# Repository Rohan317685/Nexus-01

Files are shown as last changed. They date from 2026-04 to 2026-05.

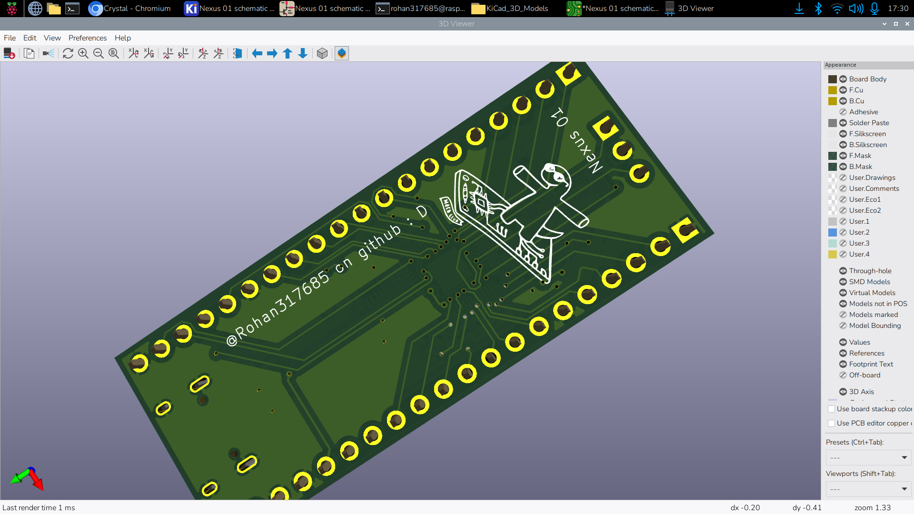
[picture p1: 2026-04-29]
images/2026-04-29-173034_1920x1080_scrot.png

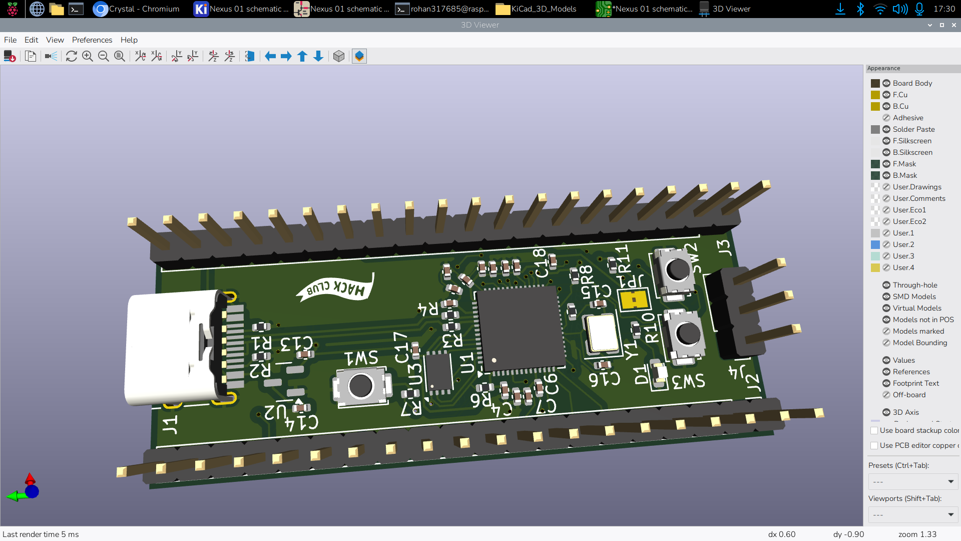
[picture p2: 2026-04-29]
images/2026-04-29-173029_1920x1080_scrot.png

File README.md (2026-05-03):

<h1 align="center">
  <br>
  Nexus 01</a>
  <br>
  Nexus 01
  <br>
</h1>

<h4 align="center">
A Raspberry Pi Pico-sized devboard!

<div align="center">



</div>

<p align="center">
  <a href="#key-features">Key Features</a> •
  <a href="#pcb">PCB</a> •
  <a href="#credits">Credits</a> •
  <a href="#license">License</a>
</p>

Devboard Banner

## Key Features

- **Raspberry Pi RP2040 chip** pico like devboard
- **Multiple LED** for visual feedback
- **USB-C**
- **2-layer PCB** designed for cheap prices at bulk
- **Panelized design** for cost-effective manufacturing
- **Multiple buttons** for reset, boot and extra inbuilt button

## PCB

Designed in KiCad with help of the hackclub blueprint guide and a few more features added!

### Schematic

Schematic

### PCB Layers

The 2-layer stackup:

**Layer 1 (Main routing layer):**

PCB Layer 1

**Layer 2 (Mainly GPIO pins):**

PCB Layer 4

**Front:**

PCB Front

**Back:**

PCB Back

### JLCPCB Order and LCSC Order

PCB Back

PCB Back

PCB Back

| Item | Description | Part Number | LCSC Code | Qty |
| :--- | :--- | :--- | :--- | :--- |
| **Tactile Switch** | SPST SMD 3.9x2.9mm | ALPS SKRKAHE020 | [C202388](https://www.lcsc.com/product-detail/C202388.html?s_z=n_q_C202388) | 10 || **3-Pin Header** | 1x3P 2.54mm Pitch TH | HX PZ2.54-1x3P ZZ | [C32713269](https://www.lcsc.com/product-detail/C32713269.html) | 5 |
| **3-Pin Header** | 1x3P 2.54mm Pitch TH | HX PZ2.54-1x3P ZZ | [C32713269](https://www.lcsc.com/product-detail/C32713269.html?s_z=n_q_C32713269) | 5 |
| **20-Pin Header** | 1x20P 2.54mm Pitch TH | PH2.54-1X20P-H25 | [C42431804](https://www.lcsc.com/product-detail/C42431804.html?s_z=n_q_C42431804) | 5 |

 (Had to get 5 because only multiples of 5 were allowed also got 10 buttons because I want to practice smd hand soldering and I will messup)
 Im buying from LCSC mainly because no companies atleast reliable companies sell those types of exact switches and those headers (I looked at aliexpress, digikey, mouser , rapid electronics and a few more and I decided this has the best price and very good shipping rates!)

### Order costs
- **Parts Total:** $2.25
- **Shipping:** $5.85
- **Handling Fee:** $3.00
- **PCBA:** $39.63
- **PCBA shipping:** $1.50
- **Overall Total:** **$52.23**
## Credits

This project uses:

- [KiCad](https://www.kicad.org/)
- [Onshape](https://www.onshape.com/) for 3D renders
- [Hack Club Macondo go join!!!](https://macondo.hackclub.com/projects/8)

## License

MIT

---

> Readme inspired by [@NotARoomba](https://github.com/NotARoomba) &nbsp;&middot;&nbsp; go follow him now!!! : D

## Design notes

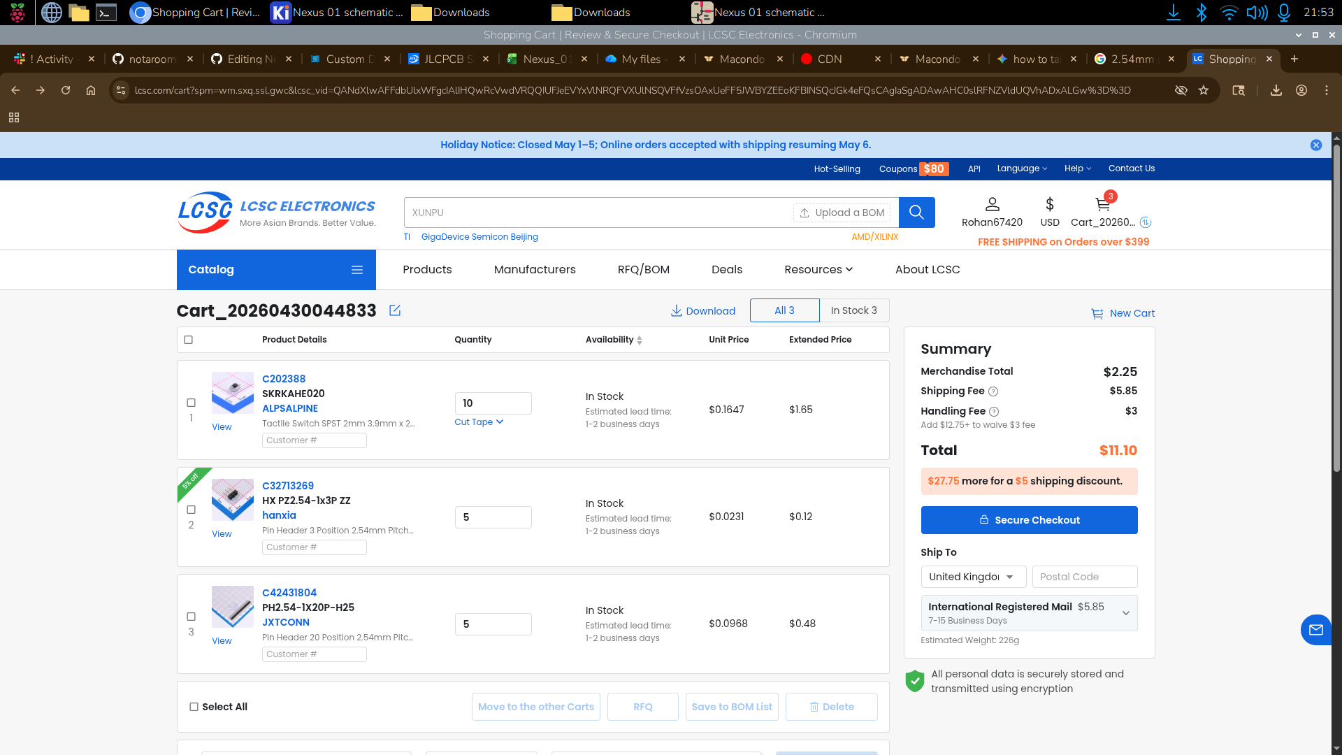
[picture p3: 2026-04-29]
images/2026-04-29-215312_1920x1080_scrot.png

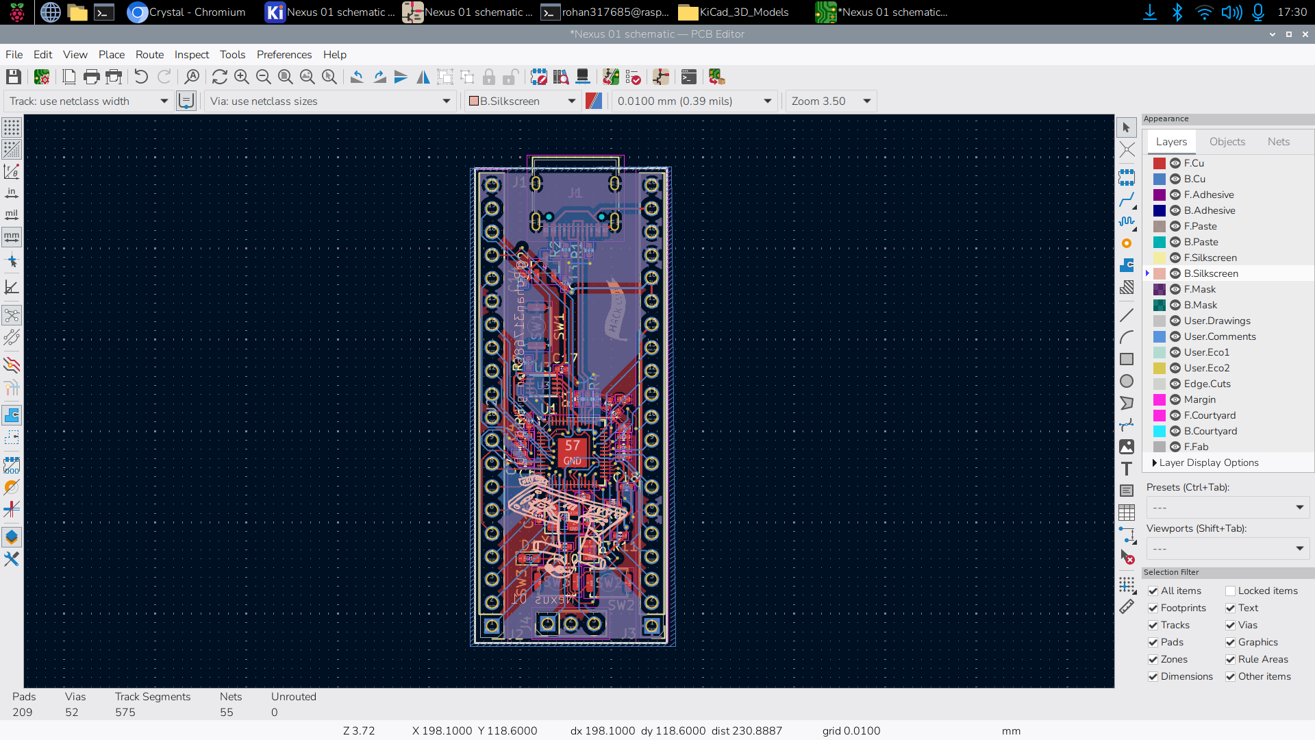
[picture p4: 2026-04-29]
images/2026-04-29-173045_1920x1080_scrot.png

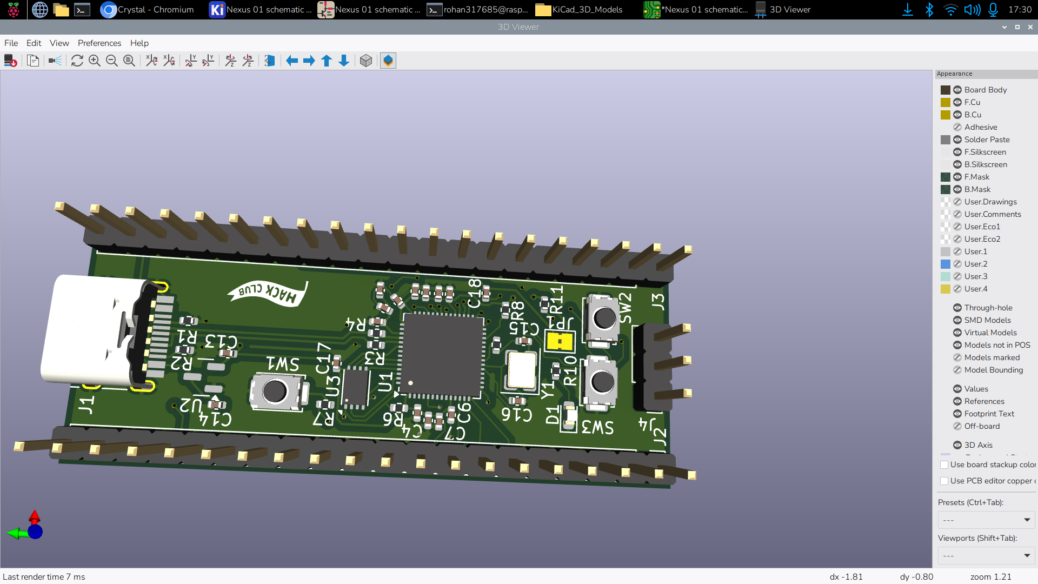
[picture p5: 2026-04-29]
images/2026-04-29-173023_1920x1080_scrot.png

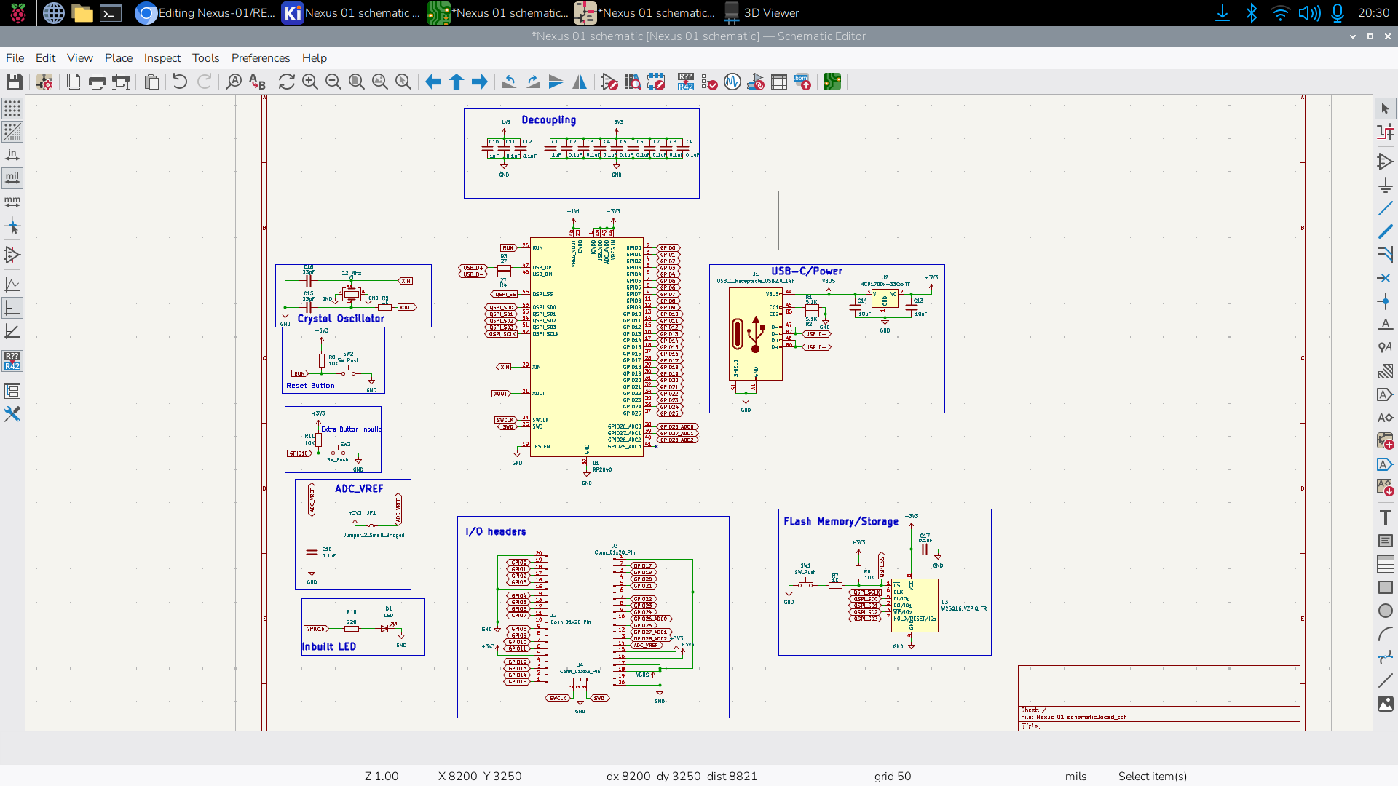
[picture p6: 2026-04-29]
images/2026-04-29-203039_1920x1080_scrot.png

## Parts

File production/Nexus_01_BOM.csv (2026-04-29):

Designator | Footprint | Quantity | Comment | LCSC Part #
C1, C10 | 402 | 2 | 1uF |  | C52923
C11, C12, C17, C18, C2, C3, C4, C5, C6, C7, C8, C9 | 402 | 12 | 0.1uF |  | C1525
C13, C14 | 402 | 2 | 10uF |  | C15525
C15, C16 | 402 | 2 | 33pF |  | C1562
D1 | 603 | 1 | LED |  | C2290
J1 | USB_C_Receptacle_HRO_TYPE-C-31-M-12 | 1 | USB_C_Receptacle_USB2.0_14P |  | C165948
J2, J3 | PinHeader_1x20_P2.54mm_Vertical | 2 | Conn_01x20_Pin
J4 | PinHeader_1x03_P2.54mm_Vertical | 1 | Conn_01x03_Pin
JP1 | SolderJumper-2_P1.3mm_Bridged2Bar_Pad1.0x1.5mm | 1 | Jumper_2_Small_Bridged
R1, R2 | 402 | 2 | 5.1K |  | C25905
R10 | 402 | 1 | 220 |  | C25091
R11, R6, R8 | 402 | 3 | 10K |  | C25744
R3, R4 | 402 | 2 | 27 |  | C25100
R5, R7 | 402 | 2 | 1K |  | C11702
SW1, SW2, SW3 | SW_Push_SPST_NO_Alps_SKRK | 3 | SW_Push |  | C115357
U1 | QFN-56-1EP_7x7mm_P0.4mm_EP3.2x3.2mm | 1 | RP2040 |  | C2040
U2 | SOT-23 | 1 | MCP1700x-330xxTT |  | C2132
U3 | Winbond_USON-8-1EP_3x2mm_P0.5mm_EP0.2x1.6mm | 1 | W25Q16JVZPIQ TR |  | C2456208
Y1 | Crystal_SMD_3225-4Pin_3.2x2.5mm | 1 | 12 MHz |  | C481407

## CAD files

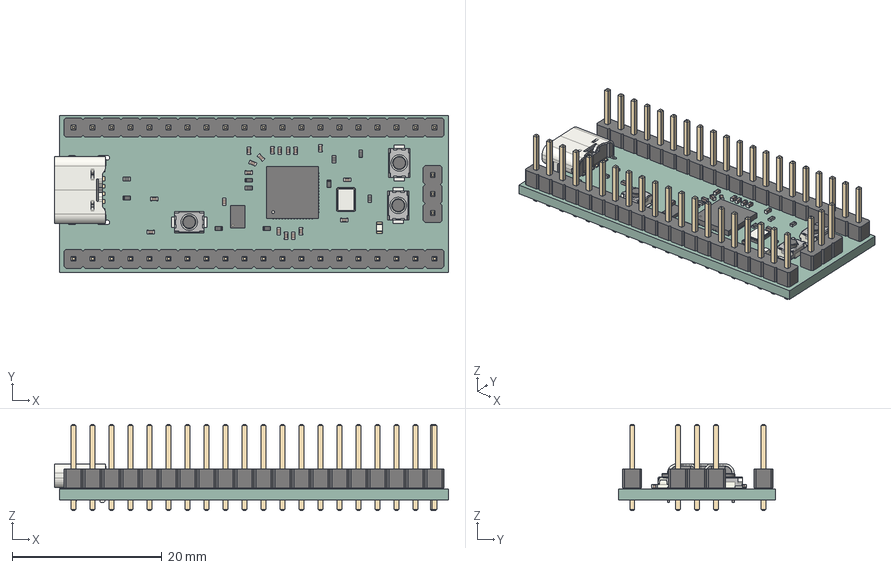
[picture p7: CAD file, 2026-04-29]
src/Nexus 01 schematic.step
52.7 x 21.0 x 11.5 mm
C_0402_1005Metric x 18
R_0402_1005Metric x 10
LED_0603_1608Metric
SW_Push_SPST_NO_Alps_SKRK x 3
PinHeader_1x20_P2.54mm_Vertical x 2
PinHeader_1x03_P2.54mm_Vertical
QFN-56-1EP_7x7mm_P0.4mm_EP3.2x3.2mm
Crystal_SMD_3225-4Pin_3.2x2.5mm
USB_C_Receptacle_GCT_USB4125-xx-x-0190_6P_TopMnt_Horizontal
Winbond_USON-8-1EP_3x2mm_P0.5mm_EP0.2x1.6mm
Nexus 01 schematic_PCB

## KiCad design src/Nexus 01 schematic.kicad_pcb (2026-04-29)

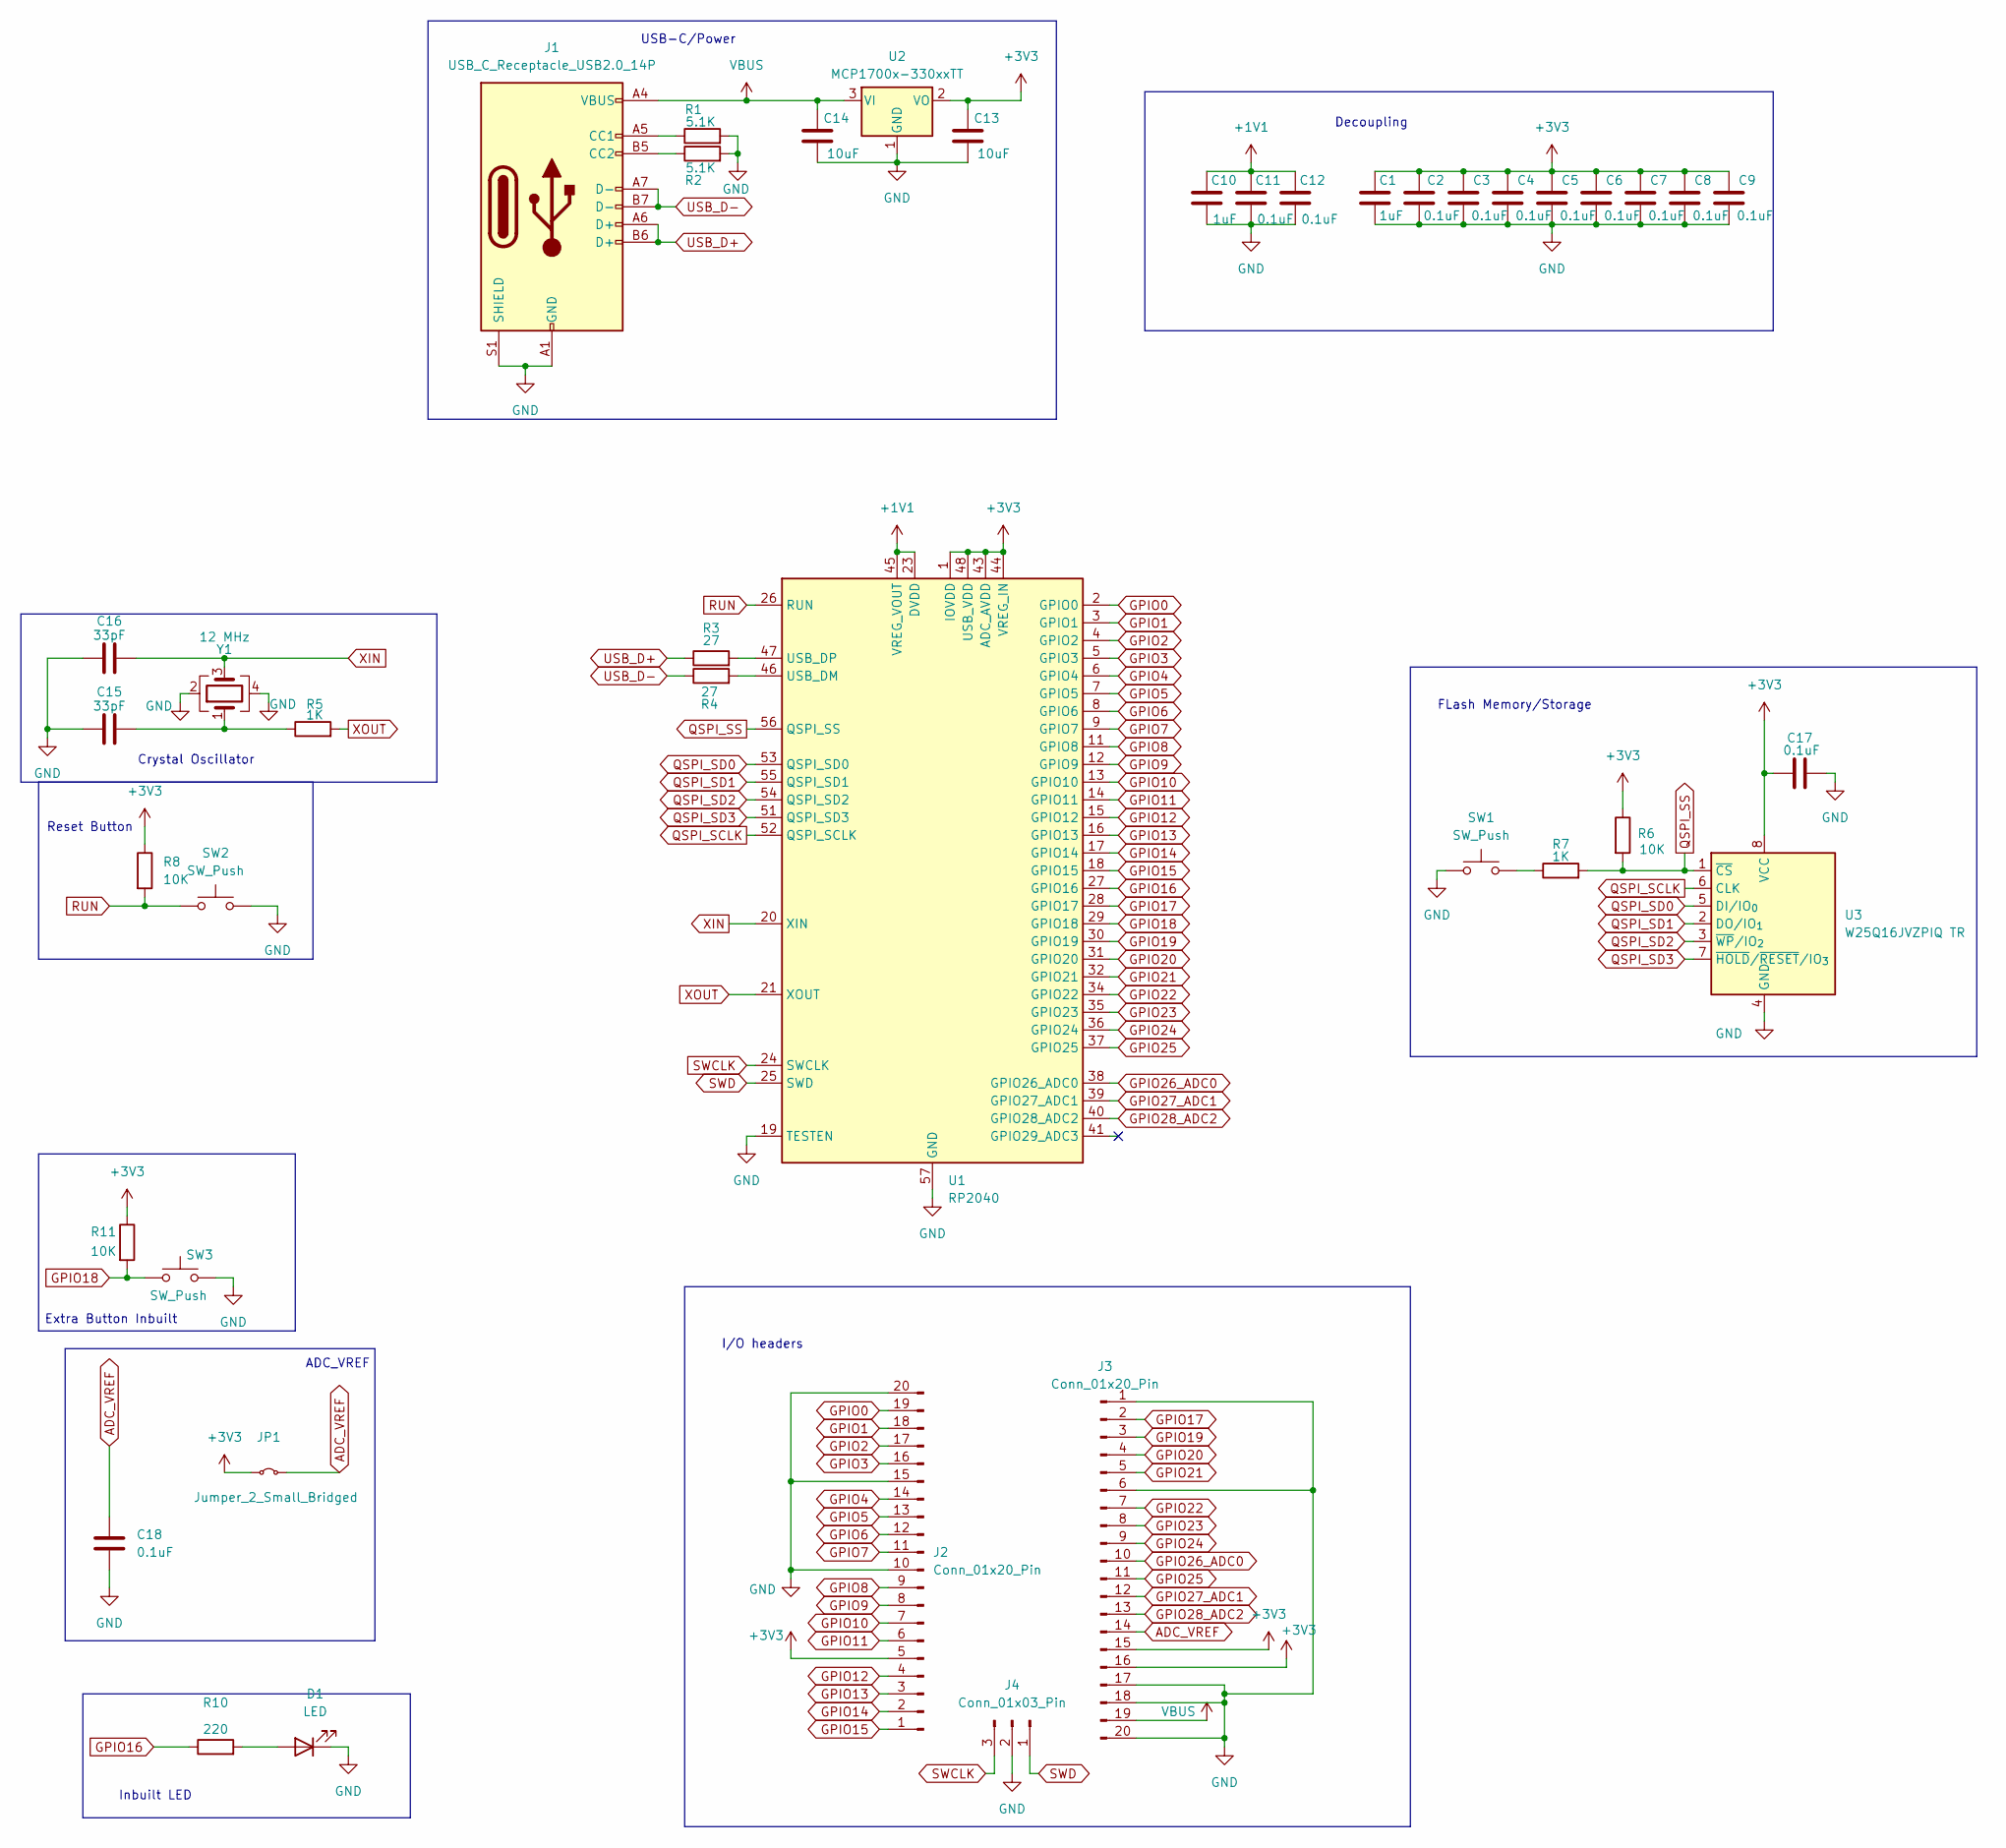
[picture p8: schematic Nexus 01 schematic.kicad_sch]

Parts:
C1, C10: 1uF; C_0402_1005Metric
C2, C3, C4, C5, C6, C7, C8, C9, C11, C12, C17, C18: 0.1uF; C_0402_1005Metric
C13, C14: 10uF; C_0402_1005Metric
C15, C16: 33pF; C_0402_1005Metric
D1: LED; LED_0603_1608Metric
J1: USB_C_Receptacle_USB2.0_14P; USB_C_Receptacle_HRO_TYPE-C-31-M-12
J2, J3: Conn_01x20_Pin; PinHeader_1x20_P2.54mm_Vertical
J4: Conn_01x03_Pin; PinHeader_1x03_P2.54mm_Vertical
JP1: Jumper_2_Small_Bridged; SolderJumper-2_P1.3mm_Bridged2Bar_Pad1.0x1.5mm
R1, R2: 5.1K; R_0402_1005Metric
R3, R4: 27; R_0402_1005Metric
R5, R7: 1K; R_0402_1005Metric
R6, R8, R11: 10K; R_0402_1005Metric
R10: 220; R_0402_1005Metric
SW1, SW2, SW3: SW_Push; SW_Push_SPST_NO_Alps_SKRK
U1: RP2040; QFN-56-1EP_7x7mm_P0.4mm_EP3.2x3.2mm
U2: MCP1700x-330xxTT; SOT-23
U3: W25Q16JVZPIQ TR; Winbond_USON-8-1EP_3x2mm_P0.5mm_EP0.2x1.6mm
Y1: 12 MHz; Crystal_SMD_3225-4Pin_3.2x2.5mm

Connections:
+1V1: C10.1, C11.1, C12.1, U1.23 (DVDD), U1.45 (VREG_VOUT), U1.50 (DVDD)
+3V3: C1.1, C2.1, C3.1, C4.1, C5.1, C6.1, C7.1, C8.1, C9.1, C13.1, C17.1, J2.5, J3.15, J3.16, JP1.1 (A), R6.1, R8.1, R11.1, U1.1 (IOVDD), U1.10 (IOVDD), U1.22 (IOVDD), U1.33 (IOVDD), U1.42 (IOVDD), U1.43 (ADC_AVDD), U1.44 (VREG_IN), U1.48 (USB_VDD), U1.49 (IOVDD), U2.2 (VO), U3.8 (VCC)
ADC_VREF: C18.1, J3.14, JP1.2 (B)
GND: C1.2, C2.2, C3.2, C4.2, C5.2, C6.2, C7.2, C8.2, C9.2, C10.2, C11.2, C12.2, C13.2, C14.2, C15.1, C16.1, C17.2, C18.2, D1.1 (K), J1.A1 (GND), J1.A12 (GND), J1.B1 (GND), J1.B12 (GND), J1.S1 (SHIELD), J2.10, J2.15, J2.20, J3.1, J3.6, J3.17, J3.18, J3.20, J4.2, R1.2, R2.2, SW1.1, SW2.2, SW3.2, U1.19 (TESTEN), U1.57 (GND), U2.1 (GND), U3.4 (GND), Y1.2, Y1.4
GPIO0: J2.19, U1.2 (GPIO0)
GPIO1: J2.18, U1.3 (GPIO1)
GPIO2: J2.17, U1.4 (GPIO2)
GPIO3: J2.16, U1.5 (GPIO3)
GPIO4: J2.14, U1.6 (GPIO4)
GPIO5: J2.13, U1.7 (GPIO5)
GPIO6: J2.12, U1.8 (GPIO6)
GPIO7: J2.11, U1.9 (GPIO7)
GPIO8: J2.9, U1.11 (GPIO8)
GPIO9: J2.8, U1.12 (GPIO9)
GPIO10: J2.7, U1.13 (GPIO10)
GPIO11: J2.6, U1.14 (GPIO11)
GPIO12: J2.4, U1.15 (GPIO12)
GPIO13: J2.3, U1.16 (GPIO13)
GPIO14: J2.2, U1.17 (GPIO14)
GPIO15: J2.1, U1.18 (GPIO15)
GPIO16: R10.1, U1.27 (GPIO16)
GPIO17: J3.2, U1.28 (GPIO17)
GPIO18: R11.2, SW3.1, U1.29 (GPIO18)
GPIO19: J3.3, U1.30 (GPIO19)
GPIO20: J3.4, U1.31 (GPIO20)
GPIO21: J3.5, U1.32 (GPIO21)
GPIO22: J3.7, U1.34 (GPIO22)
GPIO23: J3.8, U1.35 (GPIO23)
GPIO24: J3.9, U1.36 (GPIO24)
GPIO25: J3.11, U1.37 (GPIO25)
GPIO26_ADC0: J3.10, U1.38 (GPIO26_ADC0)
GPIO27_ADC1: J3.12, U1.39 (GPIO27_ADC1)
GPIO28_ADC2: J3.13, U1.40 (GPIO28_ADC2)
unnamed: C15.2, R5.1, Y1.1
unnamed: D1.2 (A), R10.2
unnamed: J1.A5 (CC1), R1.1
unnamed: J1.B5 (CC2), R2.1
unnamed: R7.1, SW1.2
unnamed: R4.2, U1.46 (USB_DM)
unnamed: R3.2, U1.47 (USB_DP)
QSPI_SCLK: U1.52 (QSPI_SCLK), U3.6 (CLK)
QSPI_SD0: U1.53 (QSPI_SD0), U3.5 (DI/IO_{0})
QSPI_SD1: U1.55 (QSPI_SD1), U3.2 (DO/IO_{1})
QSPI_SD2: U1.54 (QSPI_SD2), U3.3 (~WP/IO_{2})
QSPI_SD3: U1.51 (QSPI_SD3), U3.7 (~HOLD/~RESET/IO_{3})
QSPI_SS: R6.2, R7.2, U1.56 (QSPI_SS), U3.1 (~CS)
RUN: R8.2, SW2.1, U1.26 (RUN)
SWCLK: J4.3, U1.24 (SWCLK)
SWD: J4.1, U1.25 (SWD)
USB_D+: J1.A6 (D+), J1.B6 (D+), R3.1
USB_D-: J1.A7 (D-), J1.B7 (D-), R4.1
VBUS: C14.1, J1.A4 (VBUS), J1.A9 (VBUS), J1.B4 (VBUS), J1.B9 (VBUS), J3.19, U2.3 (VI)
XIN: C16.2, U1.20 (XIN), Y1.3
XOUT: R5.2, U1.21 (XOUT)

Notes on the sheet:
Crystal Oscillator
Inbuilt LED
Decoupling
Extra Button Inbuilt
ADC_VREF
I/O headers
FLash Memory/Storage
USB-C/Power
Reset Button

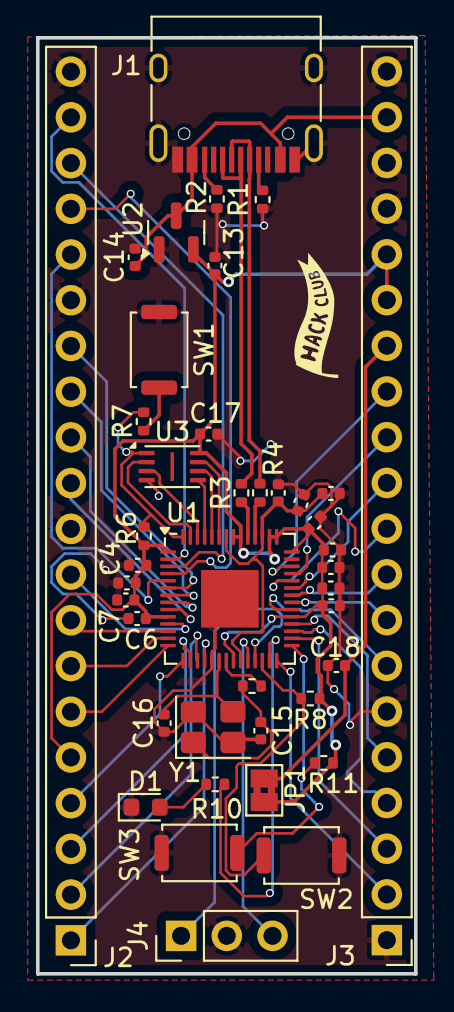
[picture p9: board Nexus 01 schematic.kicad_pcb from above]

Board: 2 copper layers, 21.0 x 52.0 mm, 41 parts (0 on the bottom side), 54 nets.

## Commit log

2026-04-29 Update overall total and add PCBA costs
2026-05-03 Fix LCSC link for 3-Pin Header in README
    Updated LCSC link for 3-Pin Header in the table.
